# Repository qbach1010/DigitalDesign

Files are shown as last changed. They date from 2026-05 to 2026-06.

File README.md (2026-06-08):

## Digital Design Project

## 📝 Project Overview

Design a 3-bit signed (X) to 3-bit signed (Y) computer, which includes operations: add, subtract, multiply, and XOR. The user can select X, Y, and the operation to compute via physical switches. 

*   **EDA Tool:** KiCad 10.0
  
*   **Dimensions:** 120 x 180 mm
  
*   **Layer Count:** 2 layers
  
*   **Primary Logic:** Computes directly through discrete logic gates: AND (CD4081), OR (CD4071), and NOT (74HC04).
  
*   **Libraries Used:** Standard KiCad library.

### 📸 Schematics & Layout

PCB Layout

Schematic Diagram

---

## 🛠️ Key Hardware Features
The main functional blocks of the schematic include:

*   **Power Supply:** Uses a 7805 voltage regulator to accept 7 ~ 14 VDC, or just using 5VDC pin to power up the circuit and provide the logic HIGH.
  
*   **Adder:** A simple 3-bit to 3-bit adder using full adders.
  
*   **Two's Complement:** Changes the sign of the 3-bit number, utilizing the adder block to also perform subtraction.
  
*   **Multiplier:** Uses **Baugh-Wooley multiplication** for multiplying the signed 3-bit numbers.
  
*   **Sign Extend:** Due to the difference between the output of the multiply operation (6 bits) and all other operations (3 bits), sign-extension logic is added to make all final outputs a uniform 6 bits wide.

---

## 🔍 Editing the Design
To view or modify the hardware files:

1. Clone this repository to your local machine.

2. Open the main `.kicad_pro` project file in **KiCad 10.0**.

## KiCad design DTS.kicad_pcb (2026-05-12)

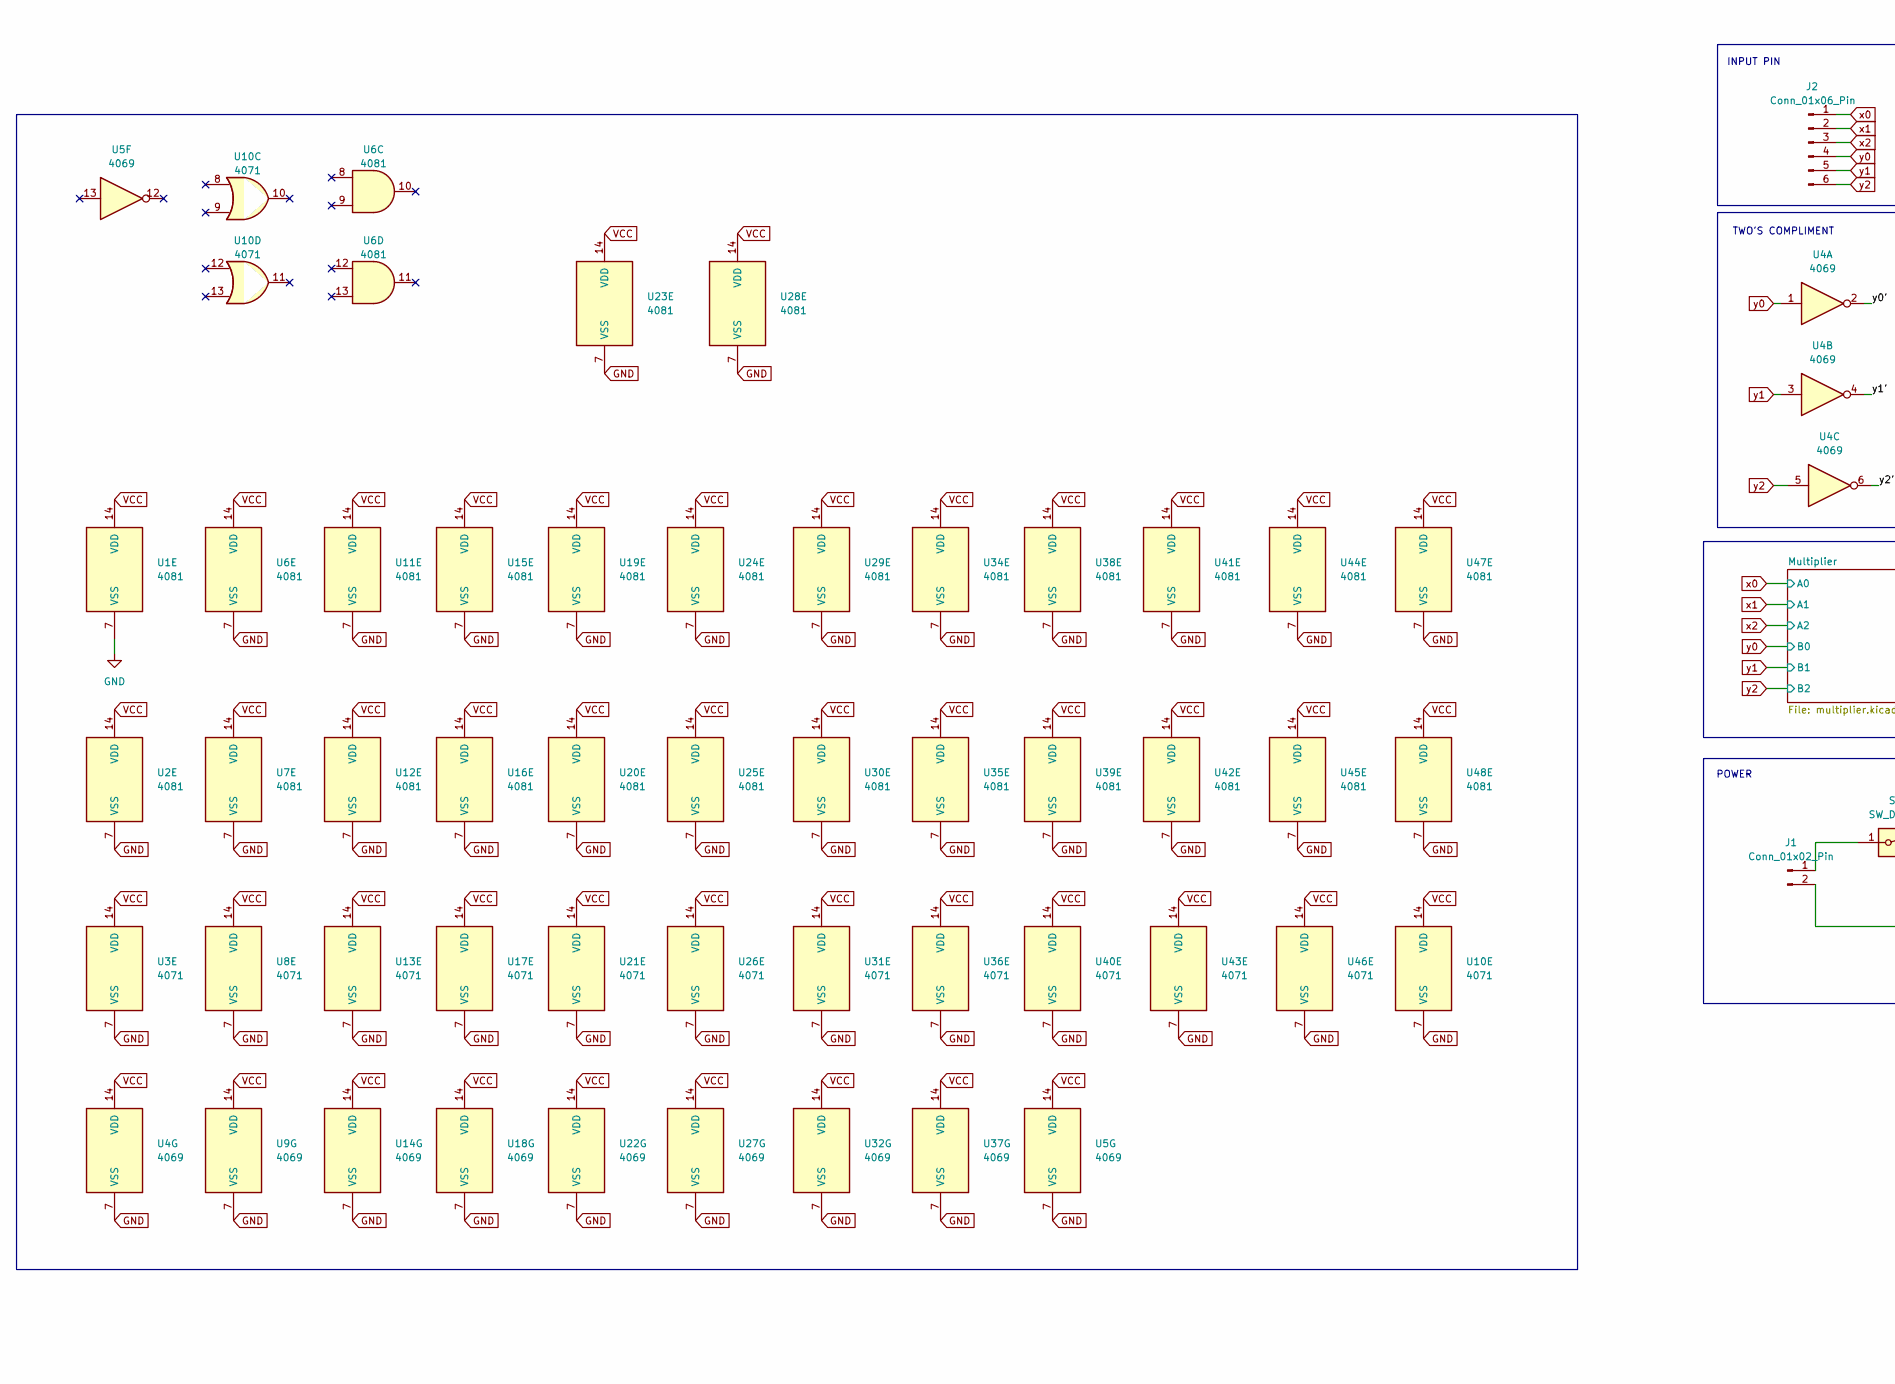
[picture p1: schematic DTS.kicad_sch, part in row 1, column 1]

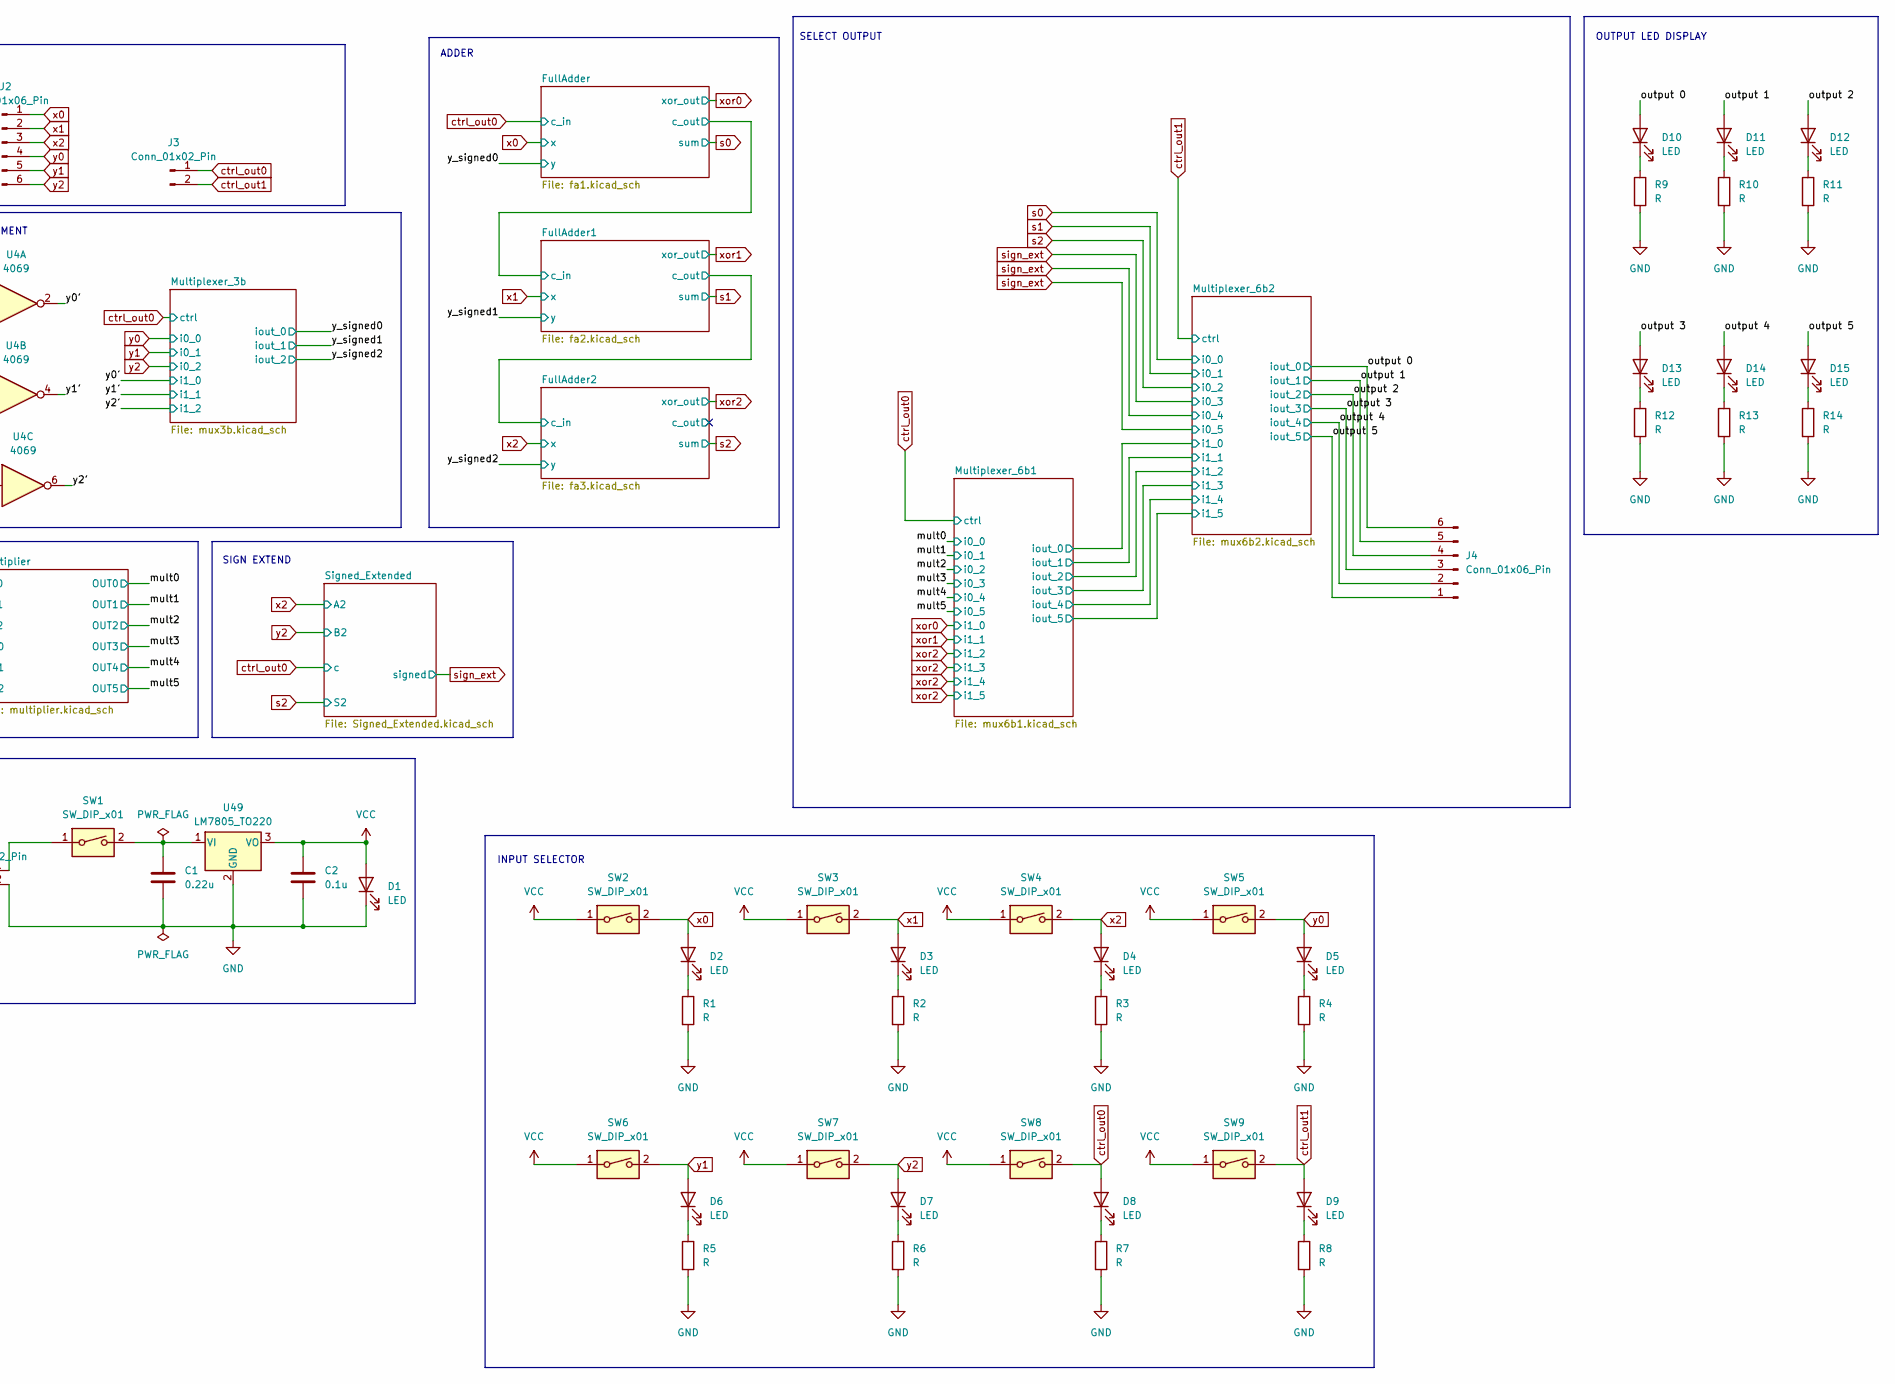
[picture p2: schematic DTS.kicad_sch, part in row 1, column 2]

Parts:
C1: 0.22u; C_Radial_D6.3mm_H5.0mm_P2.50mm
C2: 0.1u; C_Radial_D6.3mm_H5.0mm_P2.50mm
D1, D2, D3, D4, D5, D6, D7, D8, D9, D10, D11, D12, D13, D14, D15: LED; PinHeader_1x02_P2.54mm_Vertical
J1, J3: Conn_01x02_Pin; PinHeader_1x02_P2.54mm_Vertical
J2, J4: Conn_01x06_Pin; PinHeader_1x06_P2.54mm_Vertical
R1, R2, R3, R4, R5, R6, R7, R8, R9, R10, R11, R12, R13, R14: R; PinHeader_1x02_P2.54mm_Vertical
SW1, SW2, SW3, SW4, SW5, SW6, SW7, SW8, SW9: SW_DIP_x01; PinHeader_1x03_P2.54mm_Vertical
U1, U2, U6, U7, U11, U12, U15, U16, U19, U20, U23, U24, U25, U28, U29, U30, U34, U35, U38, U39, U41, U42, U44, U45, U47, U48: 4081; CERDIP-14_W7.62mm_SideBrazed_LongPads_Socket
U3, U8, U10, U13, U17, U21, U26, U31, U36, U40, U43, U46: 4071; CERDIP-14_W7.62mm_SideBrazed_LongPads_Socket
U4, U5, U9, U14, U18, U22, U27, U32, U37: 4069; CERDIP-14_W7.62mm_SideBrazed_LongPads_Socket
U49: LM7805_TO220; TO-220-3_Vertical

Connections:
/Signed_Extended/(A2^B2)': U1.5, U27.6
/Signed_Extended/(c^(A2^B2))': U1.12, U10.3
/Signed_Extended/A2': U1.2, U18.12, U48.8
/Signed_Extended/A2'B2: U46.12, U48.10
/Signed_Extended/A2'S2: U1.3, U46.8
/Signed_Extended/A2B2': U46.13, U48.4
/Signed_Extended/A2S2': U46.9, U48.11
/Signed_Extended/A2^B2: U1.8, U27.5, U46.11
/Signed_Extended/A2^S2: U1.13, U46.10
/Signed_Extended/B2': U18.10, U48.5
/Signed_Extended/S2': U6.6, U27.2, U48.12
/Signed_Extended/c': U1.6, U27.4
/Signed_Extended/c'(A2^B2)': U1.4, U10.2
/Signed_Extended/c(A2^B2): U1.10, U10.1
/Signed_Extended/overflow: U1.11, U6.5, U27.9
/Signed_Extended/overflow': U6.2, U27.8
/Signed_Extended/overflow'S2: U6.3, U10.6
/Signed_Extended/overflowS2': U6.4, U10.5
/output 0: D10.2 (A), J4.6; also elsewhere on the board
/output 1: D11.2 (A), J4.5; also elsewhere on the board
/output 2: D12.2 (A), J4.4; also elsewhere on the board
/output 3: D13.2 (A), J4.3; also elsewhere on the board
/output 4: D14.2 (A), J4.2; also elsewhere on the board
/output 5: D15.2 (A), J4.1; also elsewhere on the board
/y0': U4.2; also elsewhere on the board
/y1': U4.4; also elsewhere on the board
/y2': U4.6; also elsewhere on the board
GND: C1.2, C2.2, D1.1 (K), J1.2, R1.2, R2.2, R3.2, R4.2, R5.2, R6.2, R7.2, R8.2, R9.2, R10.2, R11.2, R12.2, R13.2, R14.2, U1.7 (VSS), U2.7 (VSS), U3.7 (VSS), U4.7 (VSS), U5.7 (VSS), U6.7 (VSS), U7.7 (VSS), U8.7 (VSS), U9.7 (VSS), U10.7 (VSS), U11.7 (VSS), U12.7 (VSS), U13.7 (VSS), U14.7 (VSS), U15.7 (VSS), U16.7 (VSS), U17.7 (VSS), U18.7 (VSS), U19.7 (VSS), U20.7 (VSS), U21.7 (VSS), U22.7 (VSS), U23.7 (VSS), U24.7 (VSS), U25.7 (VSS), U26.7 (VSS), U27.7 (VSS), U28.7 (VSS), U29.7 (VSS), U30.7 (VSS), U31.7 (VSS), U32.7 (VSS), U34.7 (VSS), U35.7 (VSS), U36.7 (VSS), U37.7 (VSS), U38.7 (VSS), U39.7 (VSS), U40.7 (VSS), U41.7 (VSS), U42.7 (VSS), U43.7 (VSS), U44.7 (VSS), U45.7 (VSS), U46.7 (VSS), U47.7 (VSS), U48.7 (VSS), U49.2 (GND); also elsewhere on the board
unnamed: D2.1 (K), R1.1
unnamed: D3.1 (K), R2.1
unnamed: D4.1 (K), R3.1
unnamed: D5.1 (K), R4.1
unnamed: D6.1 (K), R5.1
unnamed: D7.1 (K), R6.1
unnamed: D8.1 (K), R7.1
unnamed: D9.1 (K), R8.1
unnamed: D10.1 (K), R9.1
unnamed: D11.1 (K), R10.1
unnamed: D12.1 (K), R11.1
unnamed: D13.1 (K), R12.1
unnamed: D14.1 (K), R13.1
unnamed: D15.1 (K), R14.1
unnamed: J1.1, SW1.1
unnamed: C1.1, SW1.2, U49.1 (VI)
VCC: C2.1, D1.2 (A), SW2.1, SW3.1, SW4.1, SW5.1, SW6.1, SW7.1, SW8.1, SW9.1, U1.14 (VDD), U2.14 (VDD), U3.14 (VDD), U4.14 (VDD), U5.14 (VDD), U6.14 (VDD), U7.14 (VDD), U8.14 (VDD), U9.14 (VDD), U10.14 (VDD), U11.14 (VDD), U12.14 (VDD), U13.14 (VDD), U14.14 (VDD), U15.14 (VDD), U16.14 (VDD), U17.14 (VDD), U18.14 (VDD), U19.14 (VDD), U20.14 (VDD), U21.14 (VDD), U22.14 (VDD), U23.14 (VDD), U24.14 (VDD), U25.14 (VDD), U26.14 (VDD), U27.14 (VDD), U28.14 (VDD), U29.14 (VDD), U30.14 (VDD), U31.14 (VDD), U32.14 (VDD), U34.14 (VDD), U35.14 (VDD), U36.14 (VDD), U37.14 (VDD), U38.14 (VDD), U39.14 (VDD), U40.14 (VDD), U41.14 (VDD), U42.14 (VDD), U43.14 (VDD), U44.14 (VDD), U45.14 (VDD), U46.14 (VDD), U47.14 (VDD), U48.14 (VDD), U49.3 (VO); also elsewhere on the board
ctrl_out0: D8.2 (A), J3.1, SW8.2, U1.9, U27.3; also elsewhere on the board
ctrl_out1: D9.2 (A), J3.2, SW9.2; also elsewhere on the board
s2: U1.1, U6.1, U27.1; also elsewhere on the board
sign_ext: U10.4; also elsewhere on the board
x0: D2.2 (A), J2.1, SW2.2; also elsewhere on the board
x1: D3.2 (A), J2.2, SW3.2; also elsewhere on the board
x2: D4.2 (A), J2.3, SW4.2, U18.13, U48.6, U48.13; also elsewhere on the board
y0: D5.2 (A), J2.4, SW5.2, U4.1; also elsewhere on the board
y1: D6.2 (A), J2.5, SW6.2, U4.3; also elsewhere on the board
y2: D7.2 (A), J2.6, SW7.2, U4.5, U18.11, U48.9; also elsewhere on the board

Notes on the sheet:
ADDER
INPUT PIN
SIGN EXTEND
POWER
SELECT OUTPUT
OUTPUT LED DISPLAY
TWO'S COMPLIMENT
INPUT SELECTOR

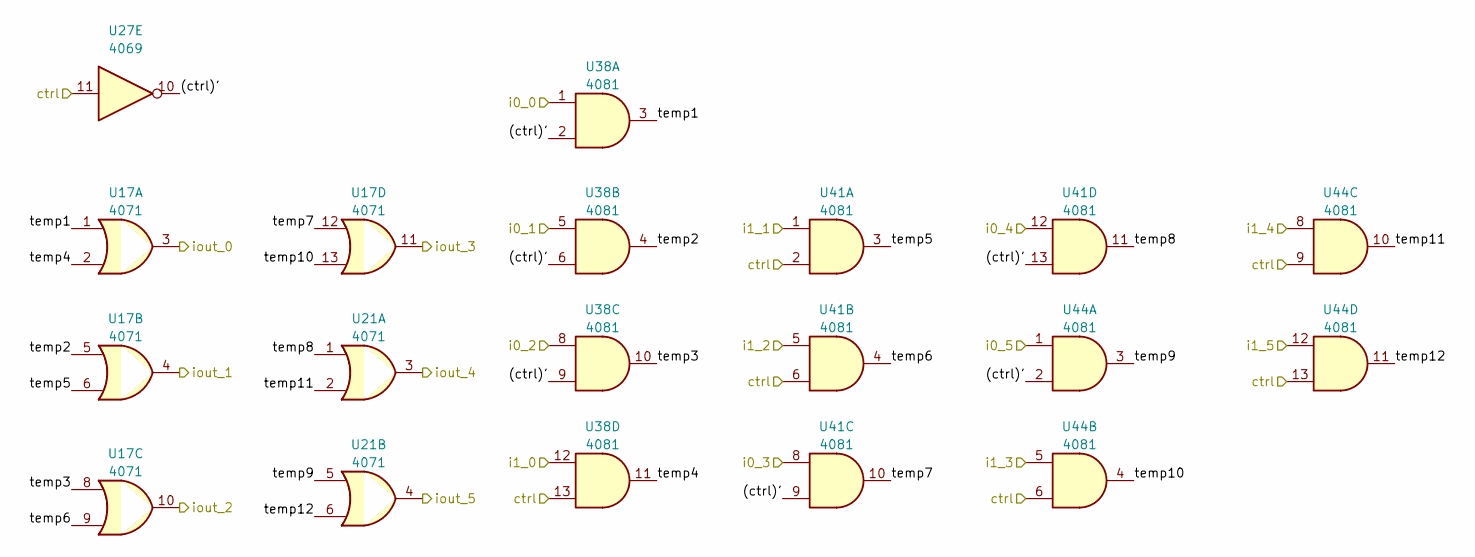
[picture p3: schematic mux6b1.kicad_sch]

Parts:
U17, U21: 4071; CERDIP-14_W7.62mm_SideBrazed_LongPads_Socket
U27: 4069; CERDIP-14_W7.62mm_SideBrazed_LongPads_Socket
U38, U41, U44: 4081; CERDIP-14_W7.62mm_SideBrazed_LongPads_Socket

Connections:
/Multiplexer_6b1/(ctrl)': U27.10, U38.2, U38.6, U38.9, U41.9, U41.13, U44.2
/Multiplexer_6b1/iout_0: U17.3; also elsewhere on the board
/Multiplexer_6b1/iout_1: U17.4; also elsewhere on the board
/Multiplexer_6b1/iout_2: U17.10; also elsewhere on the board
/Multiplexer_6b1/iout_3: U17.11; also elsewhere on the board
/Multiplexer_6b1/iout_4: U21.3; also elsewhere on the board
/Multiplexer_6b1/iout_5: U21.4; also elsewhere on the board
/Multiplexer_6b1/temp1: U17.1, U38.3
/Multiplexer_6b1/temp2: U17.5, U38.4
/Multiplexer_6b1/temp3: U17.8, U38.10
/Multiplexer_6b1/temp4: U17.2, U38.11
/Multiplexer_6b1/temp5: U17.6, U41.3
/Multiplexer_6b1/temp6: U17.9, U41.4
/Multiplexer_6b1/temp7: U17.12, U41.10
/Multiplexer_6b1/temp8: U21.1, U41.11
/Multiplexer_6b1/temp9: U21.5, U44.3
/Multiplexer_6b1/temp10: U17.13, U44.4
/Multiplexer_6b1/temp11: U21.2, U44.10
/Multiplexer_6b1/temp12: U21.6, U44.11
/Signed_Extended/(A2^B2)': U27.6; also elsewhere on the board
/Signed_Extended/A2^B2: U27.5; also elsewhere on the board
/Signed_Extended/S2': U27.2; also elsewhere on the board
/Signed_Extended/c': U27.4; also elsewhere on the board
/Signed_Extended/overflow: U27.9; also elsewhere on the board
/Signed_Extended/overflow': U27.8; also elsewhere on the board
/mult0: U38.1; also elsewhere on the board
/mult1: U38.5; also elsewhere on the board
/mult2: U38.8; also elsewhere on the board
/mult3: U41.8; also elsewhere on the board
/mult4: U41.12; also elsewhere on the board
/mult5: U44.1; also elsewhere on the board
ctrl_out0: U27.3, U27.11, U38.13, U41.2, U41.6, U44.6, U44.9, U44.13; also elsewhere on the board
s2: U27.1; also elsewhere on the board
xor0: U38.12; also elsewhere on the board
xor1: U41.1; also elsewhere on the board
xor2: U41.5, U44.5, U44.8, U44.12; also elsewhere on the board

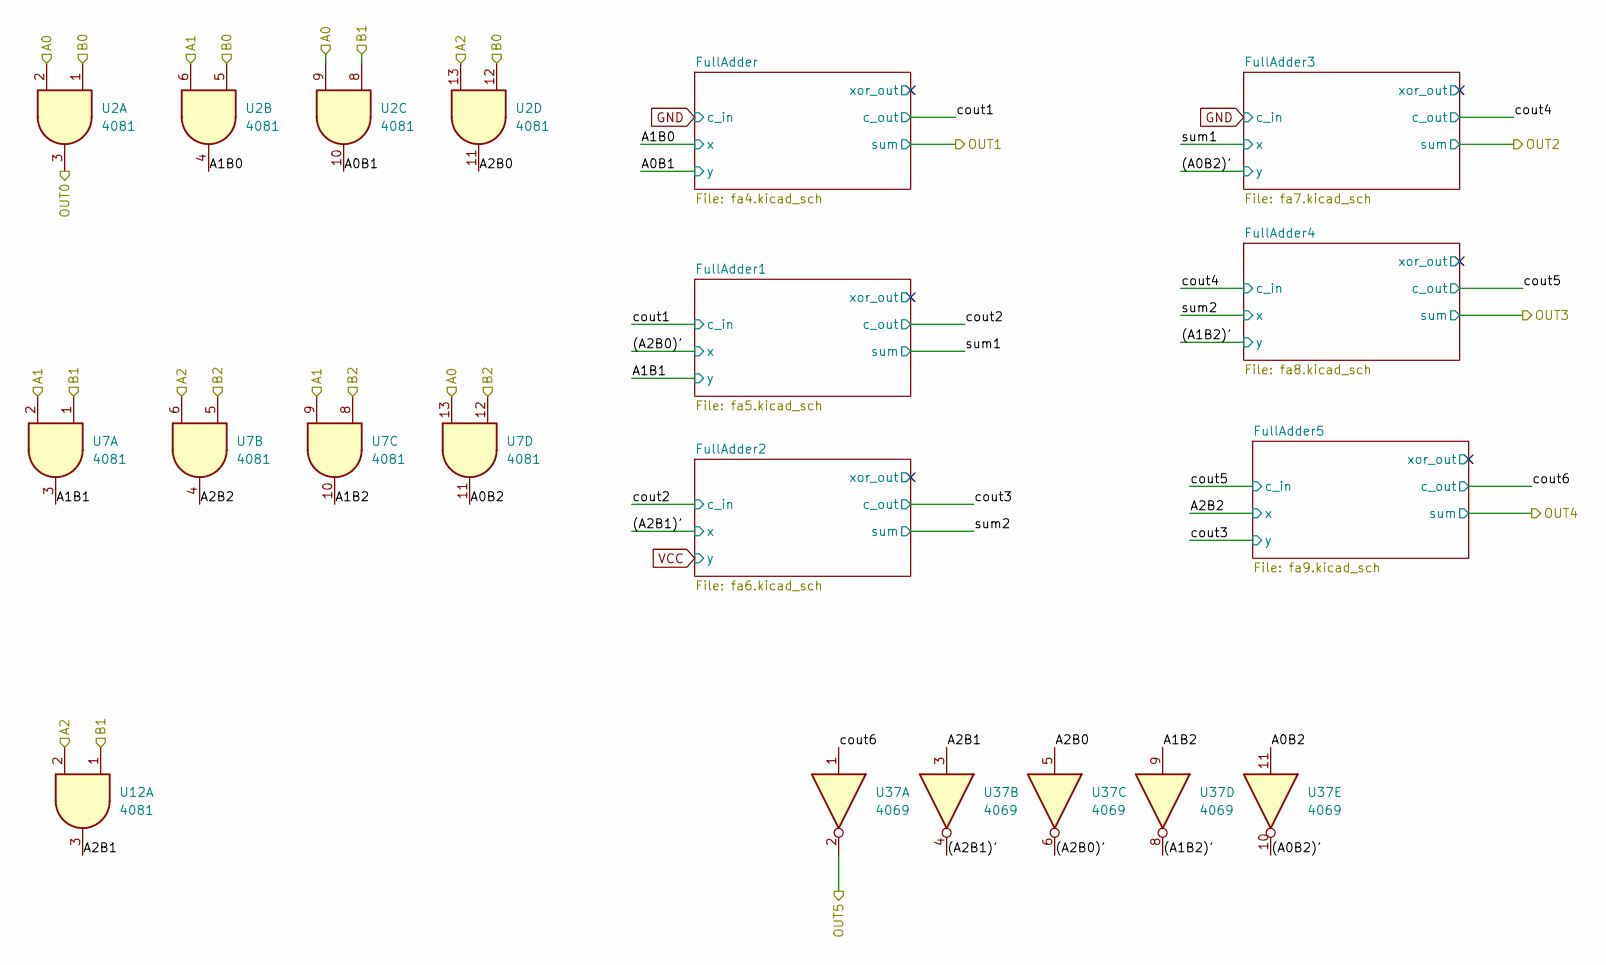
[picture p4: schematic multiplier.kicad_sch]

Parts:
U2, U7, U12: 4081; CERDIP-14_W7.62mm_SideBrazed_LongPads_Socket
U37: 4069; CERDIP-14_W7.62mm_SideBrazed_LongPads_Socket

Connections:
/Multiplier/(A0B2)': U37.10; also elsewhere on the board
/Multiplier/(A1B2)': U37.8; also elsewhere on the board
/Multiplier/(A2B0)': U37.6; also elsewhere on the board
/Multiplier/(A2B1)': U37.4; also elsewhere on the board
/Multiplier/A0B1: U2.10; also elsewhere on the board
/Multiplier/A0B2: U7.11, U37.11
/Multiplier/A1B0: U2.4; also elsewhere on the board
/Multiplier/A1B1: U7.3; also elsewhere on the board
/Multiplier/A1B2: U7.10, U37.9
/Multiplier/A2B0: U2.11, U37.5
/Multiplier/A2B1: U12.3, U37.3
/Multiplier/A2B2: U7.4; also elsewhere on the board
/Multiplier/cout6: U37.1; also elsewhere on the board
/mult0: U2.3; also elsewhere on the board
/mult5: U37.2; also elsewhere on the board
x0: U2.2, U2.9, U7.13; also elsewhere on the board
x1: U2.6, U7.2, U7.9; also elsewhere on the board
x2: U2.13, U7.6, U12.2; also elsewhere on the board
y0: U2.1, U2.5, U2.12; also elsewhere on the board
y1: U2.8, U7.1, U12.1; also elsewhere on the board
y2: U7.5, U7.8, U7.12; also elsewhere on the board

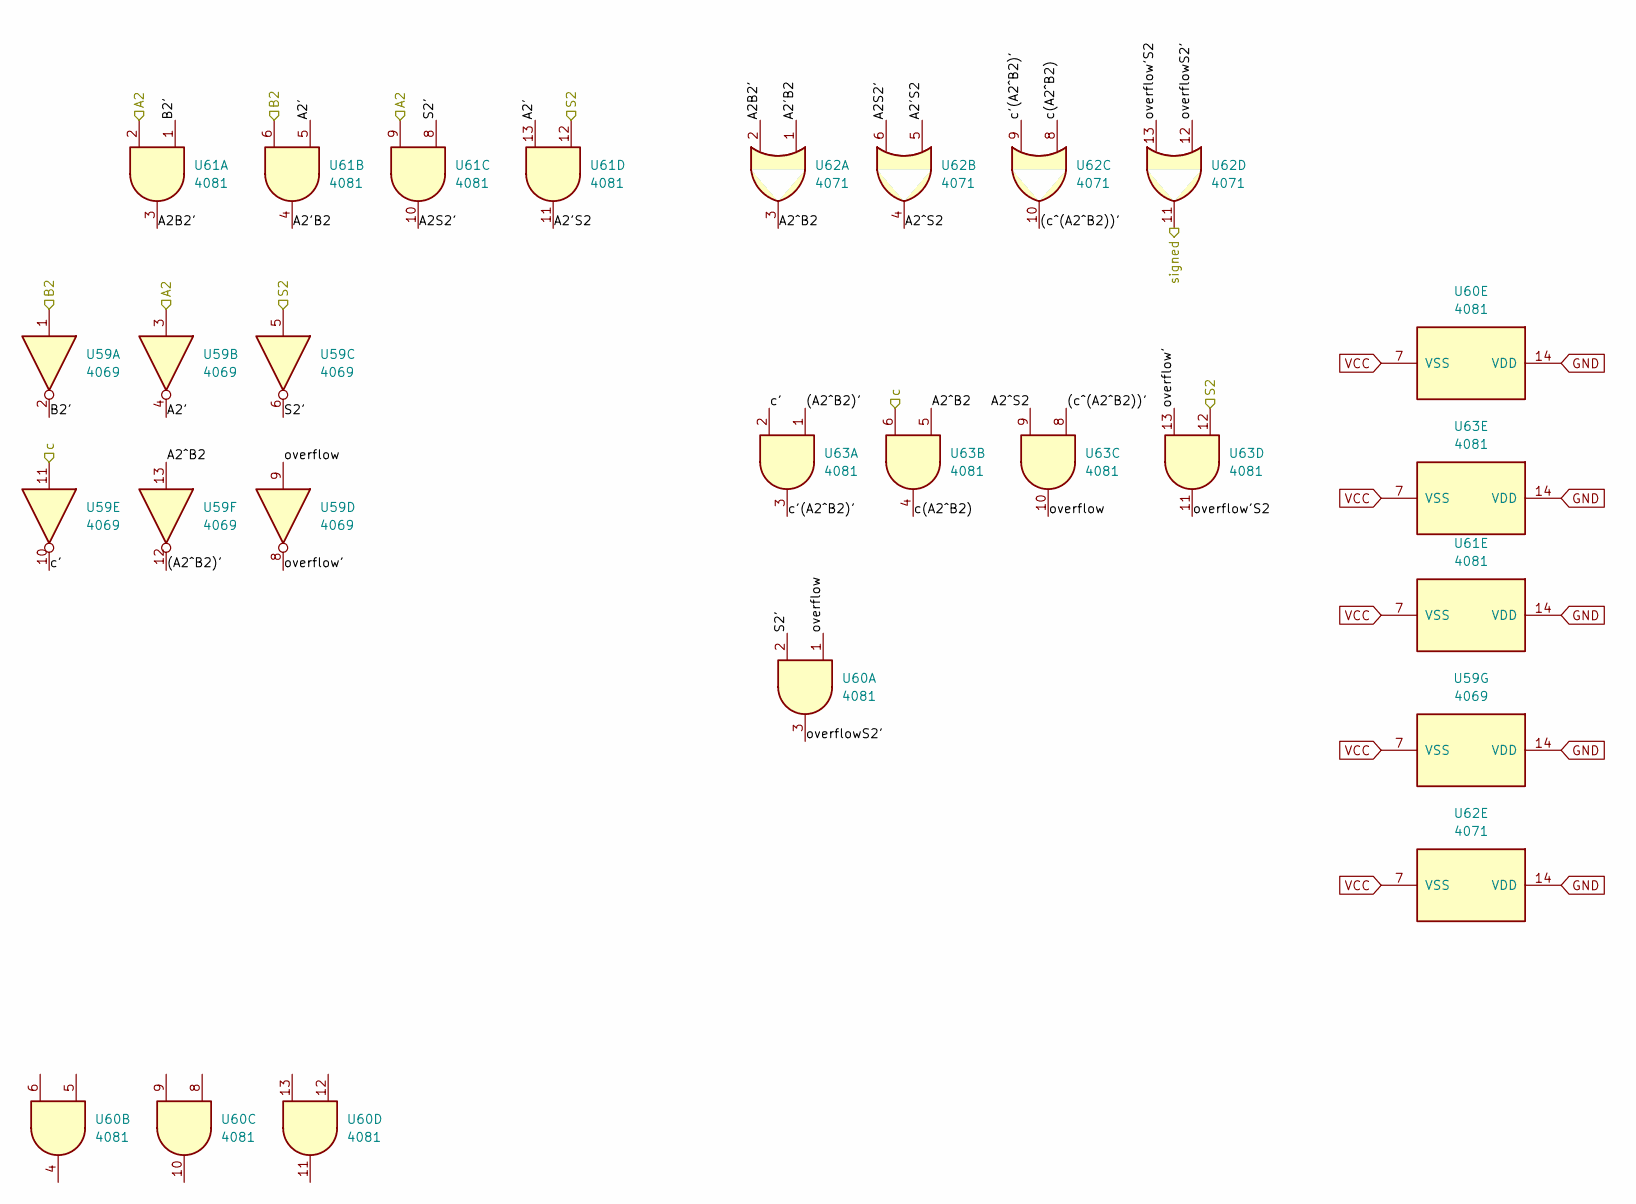
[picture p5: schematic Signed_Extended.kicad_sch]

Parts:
U59: 4069; CERDIP-14_W7.62mm_SideBrazed_LongPads_Socket
U60, U61, U63: 4081; CERDIP-14_W7.62mm_SideBrazed_LongPads_Socket
U62: 4071; CERDIP-14_W7.62mm_SideBrazed_LongPads_Socket

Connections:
unnamed: U59.1, U61.6
unnamed: U59.2, U61.1
unnamed: U59.3, U61.2, U61.9
unnamed: U59.4, U61.5, U61.13
unnamed: U59.5, U61.12, U63.12
unnamed: U59.6, U60.2, U61.8
unnamed: U59.7 (VSS), U60.7 (VSS), U61.7 (VSS), U62.7 (VSS), U63.7 (VSS)
unnamed: U59.8, U63.13
unnamed: U59.9, U60.1, U63.10
unnamed: U59.10, U63.2
unnamed: U59.11, U63.6
unnamed: U59.12, U63.1
unnamed: U59.13, U62.3, U63.5
unnamed: U59.14 (VDD), U60.14 (VDD), U61.14 (VDD), U62.14 (VDD), U63.14 (VDD)
unnamed: U60.3, U62.12
unnamed: U61.3, U62.2
unnamed: U61.4, U62.1
unnamed: U61.10, U62.6
unnamed: U61.11, U62.5
unnamed: U62.4, U63.9
unnamed: U62.8, U63.4
unnamed: U62.9, U63.3
unnamed: U62.10, U63.8
unnamed: U62.13, U63.11

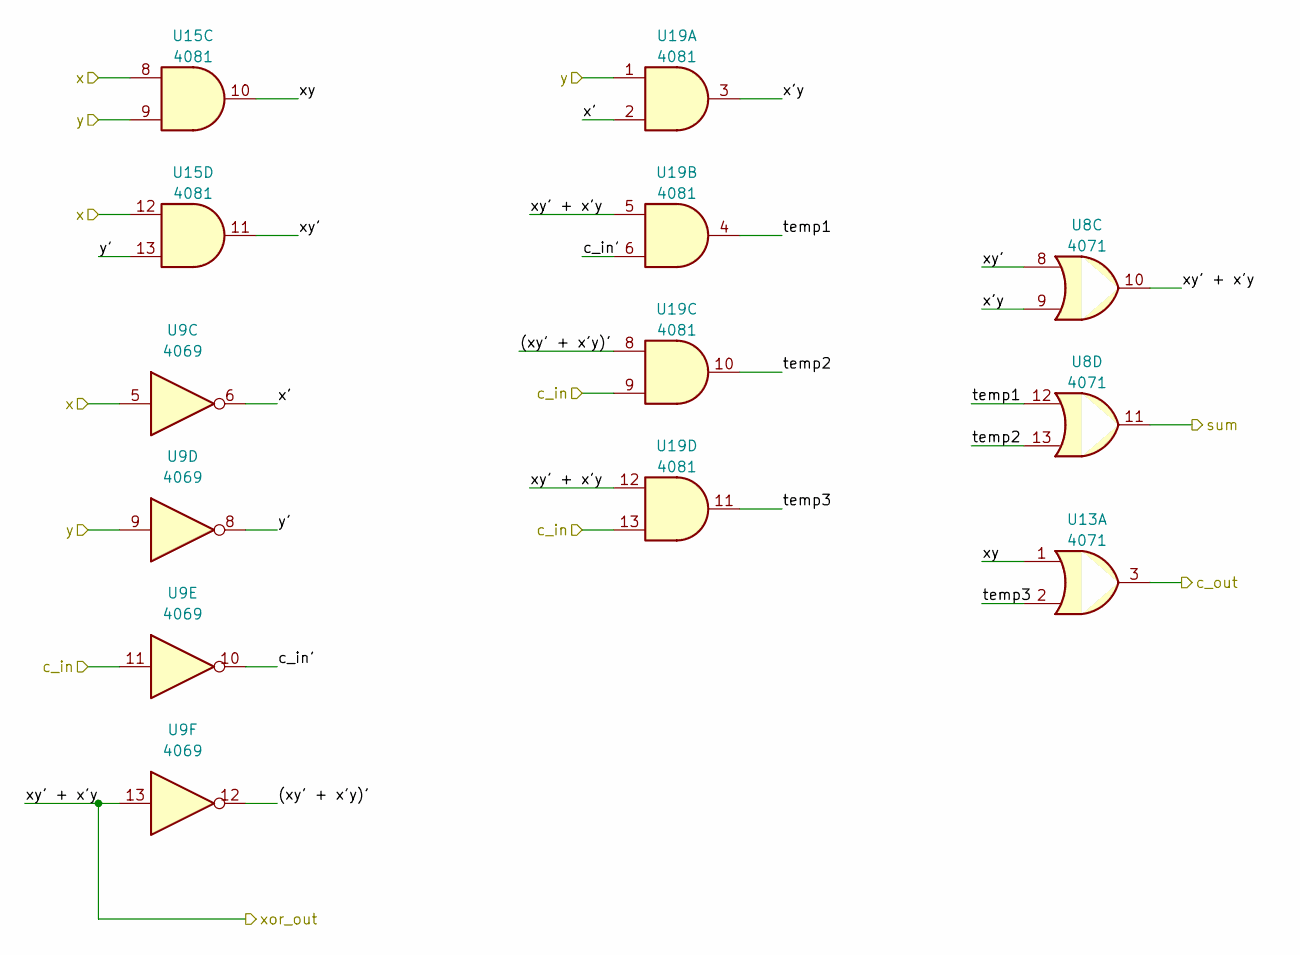
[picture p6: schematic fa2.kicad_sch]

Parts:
U8, U13: 4071; CERDIP-14_W7.62mm_SideBrazed_LongPads_Socket
U9: 4069; CERDIP-14_W7.62mm_SideBrazed_LongPads_Socket
U15, U19: 4081; CERDIP-14_W7.62mm_SideBrazed_LongPads_Socket

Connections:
/FullAdder1/(xy' + x'y)': U9.12, U19.8
/FullAdder1/c_in': U9.10, U19.6
/FullAdder1/c_out: U13.3; also elsewhere on the board
/FullAdder1/temp1: U8.12, U19.4
/FullAdder1/temp2: U8.13, U19.10
/FullAdder1/temp3: U13.2, U19.11
/FullAdder1/x': U9.6, U19.2
/FullAdder1/x'y: U8.9, U19.3
/FullAdder1/xy: U13.1, U15.10
/FullAdder1/xy': U8.8, U15.11
/FullAdder1/y': U9.8, U15.13
/FullAdder/c_out: U9.11, U19.9, U19.13; also elsewhere on the board
/y_signed1: U9.9, U15.9, U19.1; also elsewhere on the board
s1: U8.11; also elsewhere on the board
x1: U9.5, U15.8, U15.12; also elsewhere on the board
xor1: U8.10, U9.13, U19.5, U19.12; also elsewhere on the board

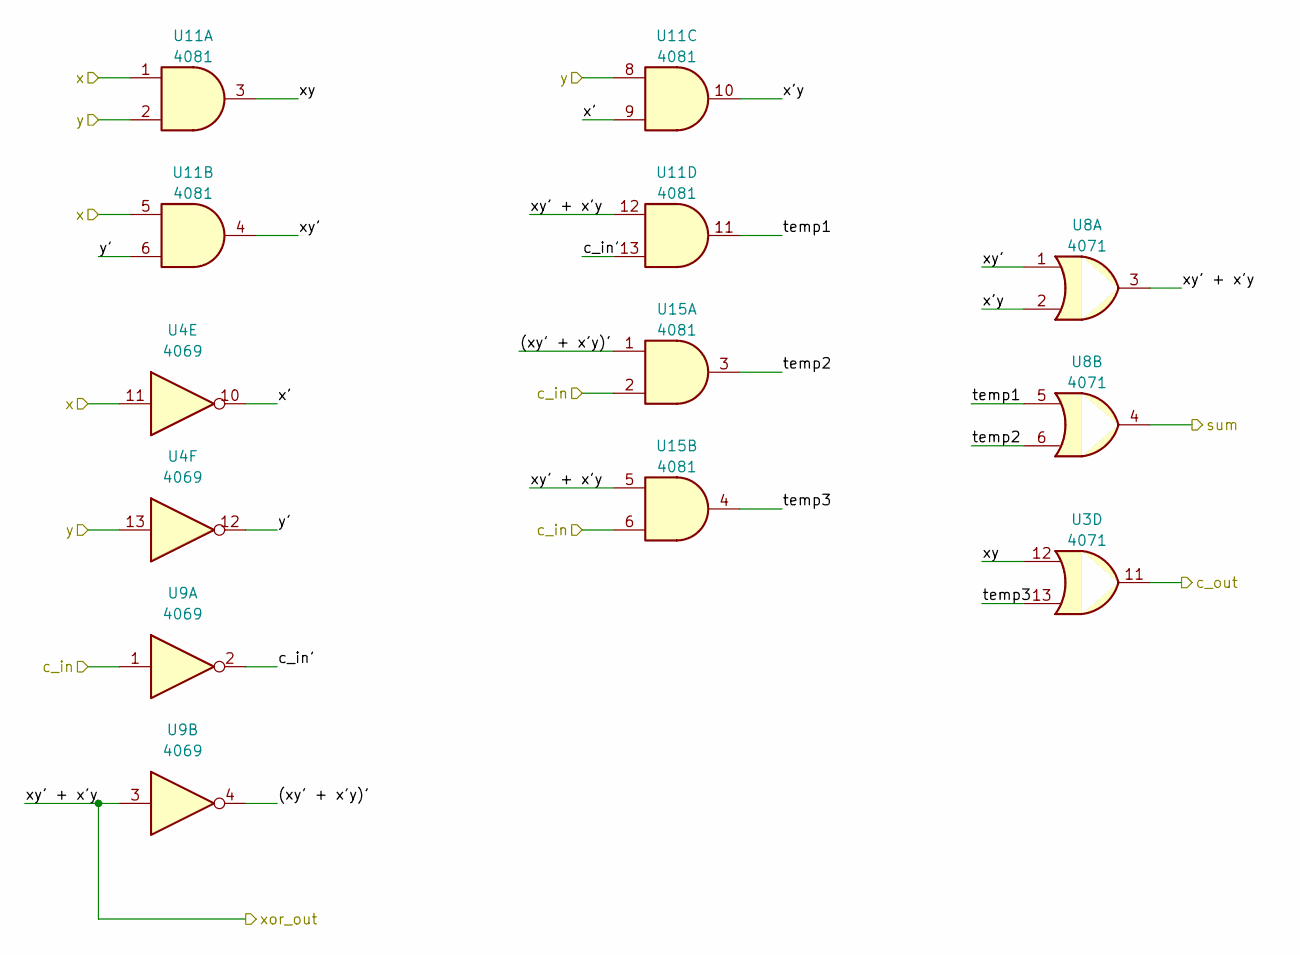
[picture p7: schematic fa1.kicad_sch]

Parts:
U3, U8: 4071; CERDIP-14_W7.62mm_SideBrazed_LongPads_Socket
U4, U9: 4069; CERDIP-14_W7.62mm_SideBrazed_LongPads_Socket
U11, U15: 4081; CERDIP-14_W7.62mm_SideBrazed_LongPads_Socket

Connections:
/FullAdder/(xy' + x'y)': U9.4, U15.1
/FullAdder/c_in': U9.2, U11.13
/FullAdder/c_out: U3.11; also elsewhere on the board
/FullAdder/temp1: U8.5, U11.11
/FullAdder/temp2: U8.6, U15.3
/FullAdder/temp3: U3.13, U15.4
/FullAdder/x': U4.10, U11.9
/FullAdder/x'y: U8.2, U11.10
/FullAdder/xy: U3.12, U11.3
/FullAdder/xy': U8.1, U11.4
/FullAdder/y': U4.12, U11.6
/y_signed0: U4.13, U11.2, U11.8; also elsewhere on the board
ctrl_out0: U9.1, U15.2, U15.6; also elsewhere on the board
s0: U8.4; also elsewhere on the board
x0: U4.11, U11.1, U11.5; also elsewhere on the board
xor0: U8.3, U9.3, U11.12, U15.5; also elsewhere on the board

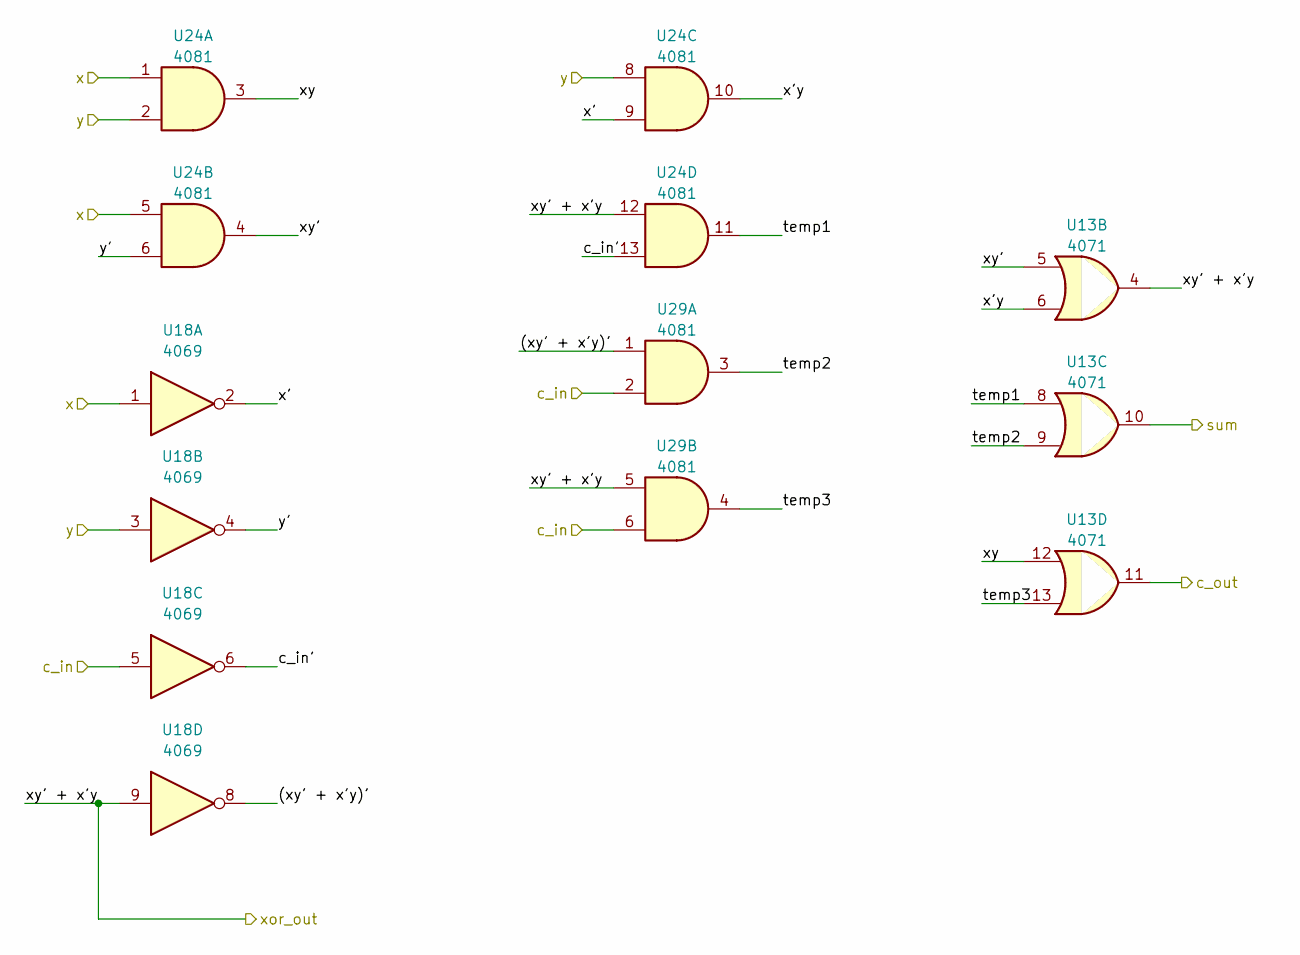
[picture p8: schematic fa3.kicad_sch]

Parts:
U13: 4071; CERDIP-14_W7.62mm_SideBrazed_LongPads_Socket
U18: 4069; CERDIP-14_W7.62mm_SideBrazed_LongPads_Socket
U24, U29: 4081; CERDIP-14_W7.62mm_SideBrazed_LongPads_Socket

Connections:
/FullAdder1/c_out: U18.5, U29.2, U29.6; also elsewhere on the board
/FullAdder2/(xy' + x'y)': U18.8, U29.1
/FullAdder2/c_in': U18.6, U24.13
/FullAdder2/c_out: U13.11
/FullAdder2/temp1: U13.8, U24.11
/FullAdder2/temp2: U13.9, U29.3
/FullAdder2/temp3: U13.13, U29.4
/FullAdder2/x': U18.2, U24.9
/FullAdder2/x'y: U13.6, U24.10
/FullAdder2/xy: U13.12, U24.3
/FullAdder2/xy': U13.5, U24.4
/FullAdder2/y': U18.4, U24.6
/Signed_Extended/A2': U18.12; also elsewhere on the board
/Signed_Extended/B2': U18.10; also elsewhere on the board
/y_signed2: U18.3, U24.2, U24.8; also elsewhere on the board
s2: U13.10; also elsewhere on the board
x2: U18.1, U18.13, U24.1, U24.5; also elsewhere on the board
xor2: U13.4, U18.9, U24.12, U29.5; also elsewhere on the board
y2: U18.11; also elsewhere on the board

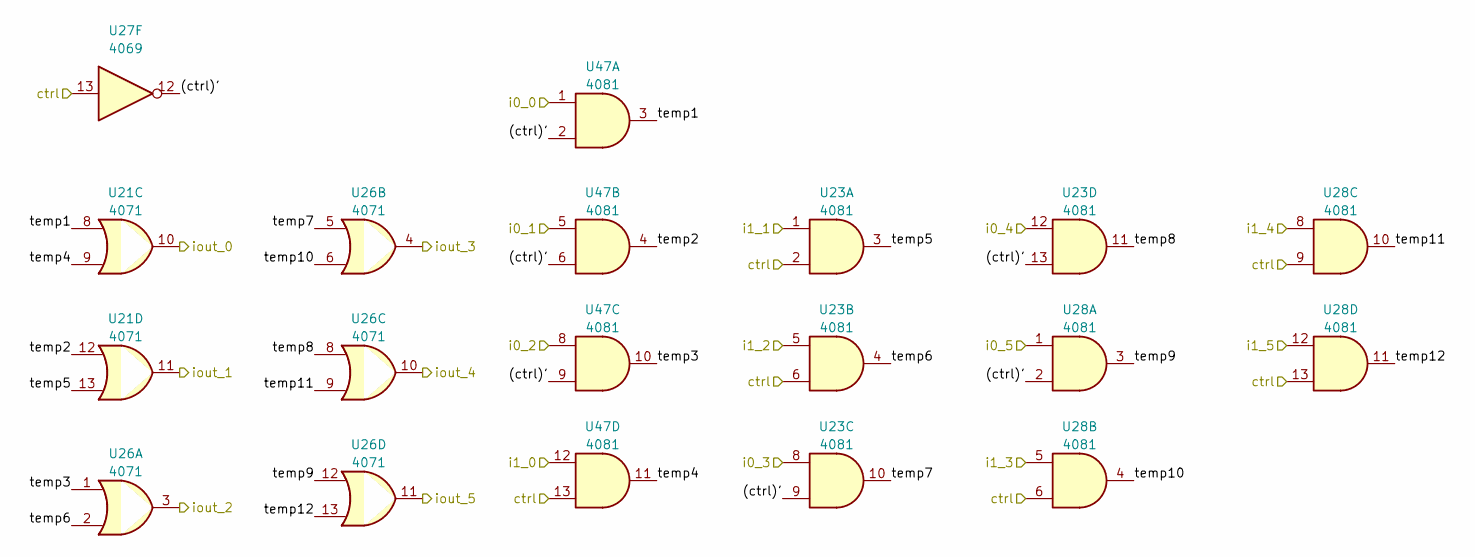
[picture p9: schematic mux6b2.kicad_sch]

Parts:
U21, U26: 4071; CERDIP-14_W7.62mm_SideBrazed_LongPads_Socket
U23, U28, U47: 4081; CERDIP-14_W7.62mm_SideBrazed_LongPads_Socket
U27: 4069; CERDIP-14_W7.62mm_SideBrazed_LongPads_Socket

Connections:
/Multiplexer_6b1/iout_0: U47.12; also elsewhere on the board
/Multiplexer_6b1/iout_1: U23.1; also elsewhere on the board
/Multiplexer_6b1/iout_2: U23.5; also elsewhere on the board
/Multiplexer_6b1/iout_3: U28.5; also elsewhere on the board
/Multiplexer_6b1/iout_4: U28.8; also elsewhere on the board
/Multiplexer_6b1/iout_5: U28.12; also elsewhere on the board
/Multiplexer_6b2/(ctrl)': U23.9, U23.13, U27.12, U28.2, U47.2, U47.6, U47.9
/Multiplexer_6b2/temp1: U21.8, U47.3
/Multiplexer_6b2/temp2: U21.12, U47.4
/Multiplexer_6b2/temp3: U26.1, U47.10
/Multiplexer_6b2/temp4: U21.9, U47.11
/Multiplexer_6b2/temp5: U21.13, U23.3
/Multiplexer_6b2/temp6: U23.4, U26.2
/Multiplexer_6b2/temp7: U23.10, U26.5
/Multiplexer_6b2/temp8: U23.11, U26.8
/Multiplexer_6b2/temp9: U26.12, U28.3
/Multiplexer_6b2/temp10: U26.6, U28.4
/Multiplexer_6b2/temp11: U26.9, U28.10
/Multiplexer_6b2/temp12: U26.13, U28.11
/Signed_Extended/(A2^B2)': U27.6; also elsewhere on the board
/Signed_Extended/A2^B2: U27.5; also elsewhere on the board
/Signed_Extended/S2': U27.2; also elsewhere on the board
/Signed_Extended/c': U27.4; also elsewhere on the board
/Signed_Extended/overflow: U27.9; also elsewhere on the board
/Signed_Extended/overflow': U27.8; also elsewhere on the board
/output 0: U21.10; also elsewhere on the board
/output 1: U21.11; also elsewhere on the board
/output 2: U26.3; also elsewhere on the board
/output 3: U26.4; also elsewhere on the board
/output 4: U26.10; also elsewhere on the board
/output 5: U26.11; also elsewhere on the board
ctrl_out0: U27.3; also elsewhere on the board
ctrl_out1: U23.2, U23.6, U27.13, U28.6, U28.9, U28.13, U47.13; also elsewhere on the board
s0: U47.1; also elsewhere on the board
s1: U47.5; also elsewhere on the board
s2: U27.1, U47.8; also elsewhere on the board
sign_ext: U23.8, U23.12, U28.1; also elsewhere on the board

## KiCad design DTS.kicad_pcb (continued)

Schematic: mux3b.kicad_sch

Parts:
U3: 4071; CERDIP-14_W7.62mm_SideBrazed_LongPads_Socket
U4: 4069; CERDIP-14_W7.62mm_SideBrazed_LongPads_Socket
U29, U34: 4081; CERDIP-14_W7.62mm_SideBrazed_LongPads_Socket

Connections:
/Multiplexer_3b/(ctrl)': U4.8, U34.2, U34.9, U34.13
/Multiplexer_3b/temp1: U3.1, U34.10
/Multiplexer_3b/temp2: U3.5, U34.11
/Multiplexer_3b/temp3: U3.8, U34.3
/Multiplexer_3b/temp4: U3.2, U34.4
/Multiplexer_3b/temp5: U3.6, U29.10
/Multiplexer_3b/temp6: U3.9, U29.11
/y0': U34.5; also elsewhere on the board
/y1': U29.8; also elsewhere on the board
/y2': U29.12; also elsewhere on the board
/y_signed0: U3.3; also elsewhere on the board
/y_signed1: U3.4; also elsewhere on the board
/y_signed2: U3.10; also elsewhere on the board
ctrl_out0: U4.9, U29.9, U29.13, U34.6; also elsewhere on the board
y0: U34.8; also elsewhere on the board
y1: U34.12; also elsewhere on the board
y2: U34.1; also elsewhere on the board

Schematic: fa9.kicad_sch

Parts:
U5: 4069; CERDIP-14_W7.62mm_SideBrazed_LongPads_Socket
U42, U45, U48: 4081; CERDIP-14_W7.62mm_SideBrazed_LongPads_Socket
U43, U46: 4071; CERDIP-14_W7.62mm_SideBrazed_LongPads_Socket

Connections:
/Multiplier/A2B2: U5.3, U42.1, U45.1; also elsewhere on the board
/Multiplier/FullAdder5/(xy' + x'y)': U5.10, U45.12
/Multiplier/FullAdder5/c_in': U5.8, U45.9
/Multiplier/FullAdder5/temp1: U45.10, U46.1
/Multiplier/FullAdder5/temp2: U45.11, U46.2
/Multiplier/FullAdder5/temp3: U46.6, U48.3
/Multiplier/FullAdder5/x': U5.4, U45.6
/Multiplier/FullAdder5/x'y: U43.13, U45.4
/Multiplier/FullAdder5/xy: U42.3, U46.5
/Multiplier/FullAdder5/xy': U43.12, U45.3
/Multiplier/FullAdder5/xy' + x'y: U5.11, U43.11, U45.8, U48.1
/Multiplier/FullAdder5/y': U5.6, U45.2
/Multiplier/cout3: U5.5, U42.2, U45.5; also elsewhere on the board
/Multiplier/cout5: U5.9, U45.13, U48.2; also elsewhere on the board
/Multiplier/cout6: U46.4; also elsewhere on the board
/Signed_Extended/A2': U48.8; also elsewhere on the board
/Signed_Extended/A2'B2: U46.12, U48.10
/Signed_Extended/A2'S2: U46.8; also elsewhere on the board
/Signed_Extended/A2B2': U46.13, U48.4
/Signed_Extended/A2S2': U46.9, U48.11
/Signed_Extended/A2^B2: U46.11; also elsewhere on the board
/Signed_Extended/A2^S2: U46.10; also elsewhere on the board
/Signed_Extended/B2': U48.5; also elsewhere on the board
/Signed_Extended/S2': U48.12; also elsewhere on the board
/mult4: U46.3; also elsewhere on the board
x2: U48.6, U48.13; also elsewhere on the board
y2: U48.9; also elsewhere on the board

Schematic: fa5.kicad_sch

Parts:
U14, U22: 4069; CERDIP-14_W7.62mm_SideBrazed_LongPads_Socket
U16, U20, U25: 4081; CERDIP-14_W7.62mm_SideBrazed_LongPads_Socket
U31, U36: 4071; CERDIP-14_W7.62mm_SideBrazed_LongPads_Socket

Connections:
/Multiplier/(A2B0)': U16.1, U20.1, U22.1; also elsewhere on the board
/Multiplier/A1B1: U14.9, U16.2, U20.5; also elsewhere on the board
/Multiplier/FullAdder1/(xy' + x'y)': U14.12, U20.12
/Multiplier/FullAdder1/c_in': U14.10, U20.9
/Multiplier/FullAdder1/temp1: U20.10, U36.5
/Multiplier/FullAdder1/temp2: U20.11, U36.6
/Multiplier/FullAdder1/temp3: U25.3, U31.13
/Multiplier/FullAdder1/x': U20.6, U22.2
/Multiplier/FullAdder1/x'y: U20.4, U36.2
/Multiplier/FullAdder1/xy: U16.3, U31.12
/Multiplier/FullAdder1/xy': U20.3, U36.1
/Multiplier/FullAdder1/xy' + x'y: U14.13, U20.8, U25.1, U36.3
/Multiplier/FullAdder1/y': U14.8, U20.2
/Multiplier/cout1: U14.11, U20.13, U25.2; also elsewhere on the board
/Multiplier/cout2: U31.11; also elsewhere on the board
/Multiplier/sum1: U36.4; also elsewhere on the board

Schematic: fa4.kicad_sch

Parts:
U12, U16: 4081; CERDIP-14_W7.62mm_SideBrazed_LongPads_Socket
U14, U37: 4069; CERDIP-14_W7.62mm_SideBrazed_LongPads_Socket
U31: 4071; CERDIP-14_W7.62mm_SideBrazed_LongPads_Socket

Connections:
/Multiplier/A0B1: U12.6, U12.12, U14.1; also elsewhere on the board
/Multiplier/A1B0: U12.5, U12.8, U37.13; also elsewhere on the board
/Multiplier/FullAdder/(xy' + x'y)': U14.6, U16.8
/Multiplier/FullAdder/c_in': U14.4, U16.6
/Multiplier/FullAdder/temp1: U16.4, U31.5
/Multiplier/FullAdder/temp2: U16.10, U31.6
/Multiplier/FullAdder/temp3: U16.11, U31.9
/Multiplier/FullAdder/x': U12.13, U37.12
/Multiplier/FullAdder/x'y: U12.11, U31.2
/Multiplier/FullAdder/xy: U12.4, U31.8
/Multiplier/FullAdder/xy': U12.10, U31.1
/Multiplier/FullAdder/xy' + x'y: U14.5, U16.5, U16.12, U31.3
/Multiplier/FullAdder/y': U12.9, U14.2
/Multiplier/cout1: U31.10; also elsewhere on the board
/mult1: U31.4; also elsewhere on the board
GND: U14.3, U16.9, U16.13; also elsewhere on the board

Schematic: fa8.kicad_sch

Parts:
U5, U32: 4069; CERDIP-14_W7.62mm_SideBrazed_LongPads_Socket
U39, U42: 4081; CERDIP-14_W7.62mm_SideBrazed_LongPads_Socket
U43: 4071; CERDIP-14_W7.62mm_SideBrazed_LongPads_Socket

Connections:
/Multiplier/(A1B2)': U32.11, U39.6, U39.12; also elsewhere on the board
/Multiplier/FullAdder4/(xy' + x'y)': U5.2, U42.8
/Multiplier/FullAdder4/c_in': U32.12, U42.6
/Multiplier/FullAdder4/temp1: U42.4, U43.5
/Multiplier/FullAdder4/temp2: U42.10, U43.6
/Multiplier/FullAdder4/temp3: U42.11, U43.9
/Multiplier/FullAdder4/x': U32.8, U39.13
/Multiplier/FullAdder4/x'y: U39.11, U43.2
/Multiplier/FullAdder4/xy: U39.4, U43.8
/Multiplier/FullAdder4/xy': U39.10, U43.1
/Multiplier/FullAdder4/xy' + x'y: U5.1, U42.5, U42.12, U43.3
/Multiplier/FullAdder4/y': U32.10, U39.9
/Multiplier/cout4: U32.13, U42.9, U42.13; also elsewhere on the board
/Multiplier/cout5: U43.10; also elsewhere on the board
/Multiplier/sum2: U32.9, U39.5, U39.8; also elsewhere on the board
/mult3: U43.4; also elsewhere on the board

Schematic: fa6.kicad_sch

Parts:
U22: 4069; CERDIP-14_W7.62mm_SideBrazed_LongPads_Socket
U25, U30: 4081; CERDIP-14_W7.62mm_SideBrazed_LongPads_Socket
U36, U40: 4071; CERDIP-14_W7.62mm_SideBrazed_LongPads_Socket

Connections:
/Multiplier/(A2B1)': U22.3, U25.5, U25.8; also elsewhere on the board
/Multiplier/FullAdder2/(xy' + x'y)': U22.10, U30.8
/Multiplier/FullAdder2/c_in': U22.8, U30.6
/Multiplier/FullAdder2/temp1: U30.4, U36.8
/Multiplier/FullAdder2/temp2: U30.10, U36.9
/Multiplier/FullAdder2/temp3: U30.11, U36.13
/Multiplier/FullAdder2/x': U22.4, U25.13
/Multiplier/FullAdder2/x'y: U25.11, U40.2
/Multiplier/FullAdder2/xy: U25.4, U36.12
/Multiplier/FullAdder2/xy': U25.10, U40.1
/Multiplier/FullAdder2/xy' + x'y: U22.11, U30.5, U30.12, U40.3
/Multiplier/FullAdder2/y': U22.6, U25.9
/Multiplier/cout2: U22.9, U30.9, U30.13; also elsewhere on the board
/Multiplier/cout3: U36.11; also elsewhere on the board
/Multiplier/sum2: U36.10; also elsewhere on the board
VCC: U22.5, U25.6, U25.12; also elsewhere on the board

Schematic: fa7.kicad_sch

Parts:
U22, U32: 4069; CERDIP-14_W7.62mm_SideBrazed_LongPads_Socket
U30, U35, U39: 4081; CERDIP-14_W7.62mm_SideBrazed_LongPads_Socket
U40: 4071; CERDIP-14_W7.62mm_SideBrazed_LongPads_Socket

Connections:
/Multiplier/(A0B2)': U30.2, U32.1, U35.5; also elsewhere on the board
/Multiplier/FullAdder3/(xy' + x'y)': U32.6, U35.12
/Multiplier/FullAdder3/c_in': U32.4, U35.9
/Multiplier/FullAdder3/temp1: U35.10, U40.8
/Multiplier/FullAdder3/temp2: U35.11, U40.9
/Multiplier/FullAdder3/temp3: U39.3, U40.13
/Multiplier/FullAdder3/x': U22.12, U35.6
/Multiplier/FullAdder3/x'y: U35.4, U40.6
/Multiplier/FullAdder3/xy: U30.3, U40.12
/Multiplier/FullAdder3/xy': U35.3, U40.5
/Multiplier/FullAdder3/xy' + x'y: U32.5, U35.8, U39.1, U40.4
/Multiplier/FullAdder3/y': U32.2, U35.2
/Multiplier/cout4: U40.11; also elsewhere on the board
/Multiplier/sum1: U22.13, U30.1, U35.1; also elsewhere on the board
/mult2: U40.10; also elsewhere on the board
GND: U32.3, U35.13, U39.2; also elsewhere on the board

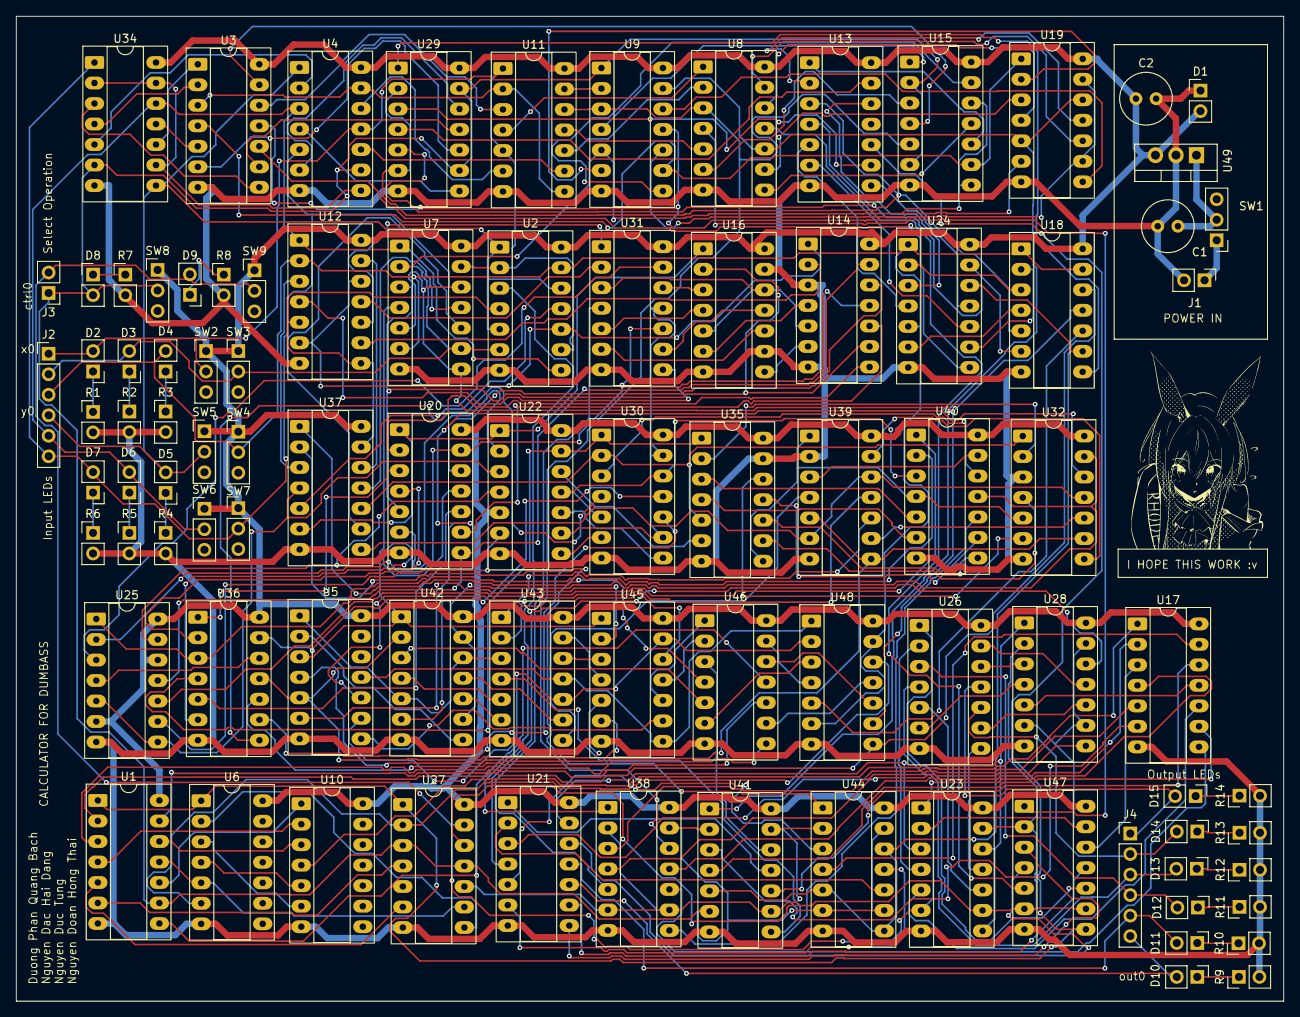
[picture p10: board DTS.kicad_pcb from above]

Board: 2 copper layers, 157.0 x 122.0 mm, 92 parts (0 on the bottom side), 226 nets.

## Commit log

2026-04-08 Add files via upload
    Added 3 bits 2:1 and 6 bits 4:1 multiplexer
    Added minus operation
    [DTS.kicad_pcb, DTS.kicad_sch, FullAdder.kicad_sch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]
2026-04-12 Add files via upload
    Waiting for approval
    [DTS.kicad_sch, FullAdder.kicad_sch, Signed_Extended.kicad_sch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]
2026-05-01 Delete DTS.kicad_pcb
    remove the original pcb design
    [DTS.kicad_pcb]
2026-05-01 Add files via upload
    This is my new pcb design file, please review
    [DTS.kicad_pcb]
2026-05-01 Delete DTS.kicad_pcb
    this is the "hasnt fixxed" file
    [DTS.kicad_pcb]
